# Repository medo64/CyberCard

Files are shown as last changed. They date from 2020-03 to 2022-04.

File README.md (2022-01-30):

[CyberCard](https://medo64.com/cybercard/)
==========================================

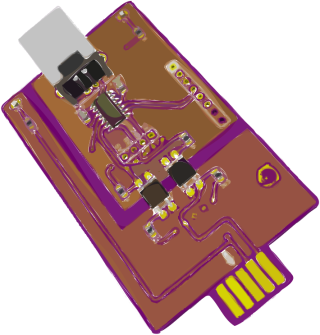
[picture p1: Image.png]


This USB device will show up on your system as a serial device and allow for a
fully isolated serial communication with CyberPower UPS devices that have support
for RMCARD202/RMCARD205 interface.

It was inspired with [Jeff Mayes Serial Interface](https://www.jmayes.com/cyberpower-backup-serial-protocol-and-interface/)
and wouldn't be possible without his extensive research.

To connect to the device, access serial device using 2400,8,N,1 (2,400 baud rate,
8 data bits, no parity, 1 stop bit) parameters. Protocol is described [here](PROTOCOL.md).

Tested devices:
* OR500LCDRM1U
* OR700LCDRM1U

---

*You can check my blog and other projects at [www.medo64.com](https://www.medo64.com/electronics/).*

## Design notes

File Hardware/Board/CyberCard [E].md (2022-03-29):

### CyberCard Parts ###

|  # | Part | RefDes  | Part Number | Alternate |
|---:|---|---|---|---|
|  1 | C 100nF X7R 16V (0805) | C4-C5 | 1276-1003-1-ND | 1276-2444-1-ND |
|  1 | C 470nF X7R 16V (0805) | C4-C5 | 1276-1074-1-ND | 1276-1199-1-ND |
|  2 | DS LED (0805) | DS1-DS2 | 475-1278-1-ND | L171L-LWC-TR |
|  1 | J USB B, horizontal | J1 | ED2982-ND | ED2983-ND |
|  3 | R 1.0K 0.125W (0805) | R1-R3 | RMCF0805FT1K00CT-ND | RMCF0805JT1K00CT-ND |
|  3 | R 2.2K 0.125W (0805) | R4-R6 | RMCF0805FT3K30CT-ND | RMCF0805JT3K30CT-ND |
|  1 | U MCP2221A-I/SL (SOIC-14) | U1 | MCP2221A-I/SL | MCP2221-I/SL-ND |
|  2 | U PC817C (SMD-4) | U2-U3 | 732-140817143200CT-ND | ISP817CXSMCT-ND |

#### Board Size ####

| | Dimensions | Area | Thickness |
|---|---|---|---|
| PCB |  75.0 x 42.5 mm | 5.0 in² | 1.6 mm |
| Panel |  54.0 x 36.5 mm | 3.1 in² | 1.6 mm |

#### Power ####

| Property | Value  |
|---|---:|
| Voltage  | 5 V |
| Current  | 100 mA |

### TTL UART Board ###

If only TTL UART access is required, the following components should be omitted:
  * C1
  * C2
  * DS1
  * J1
  * R3
  * U1

Instead of the components used, 4-pin male right-angle header should be placed
with a standard 5V USB to TTL serial cable connected to it. While 5V TTL cable
is preferred, the device should work with 3.3V TTL cable too.

A dab of hot glue is suggested on the connection to prevent accidental unplug.

On the computer side, serial port should be accessed using the following serial
port parameters: 2400,8,N,1.

### Microcontroller Controlled Board

If one desires more flexibility, MCP2221A UART can be replaced by pin-compatible
PIC16F1454 or PIC16F1455. This allows for a bit more flexibility when connecting
to UPS (e.g. no need to care about baud rate). Firmware is available as part of
this project.

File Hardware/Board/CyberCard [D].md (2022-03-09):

### CyberCard Parts ###

|  # | Part | RefDes  | Part Number | Alternate |
|---:|---|---|---|---|
|  2 | C 100nF X7R 16V (0805) | C4-C5 | 1276-1003-1-ND | 1276-2444-1-ND |
|  2 | C 470nF X7R 16V (0805) | C4-C5 | 1276-1074-1-ND | 1276-1199-1-ND |
|  2 | DS LED (0805) | DS1-DS2 | 475-1278-1-ND | L171L-LWC-TR |
|  1 | J USB B, horizontal | J1 | ED2982-ND | ED2983-ND |
|  6 | R 1.0K 0.125W (0805) | R1-R6 | RMCF0805FT1K00CT-ND | RMCF0805JT1K00CT-ND |
|  1 | U MCP2221A-I/SL (SOIC-14) | U1 | MCP2221A-I/SL | MCP2221-I/SL-ND |
|  2 | U PC817C (SMD-4) | U2-U3 | 732-140817143200CT-ND | ISP817CXSMCT-ND |
|  1 | VR L78L05ACD13TR (SO-8) | VR1 | 497-1180-1-ND | MC78L05ACDR2GOSCT-ND |

#### Board Size ####

| | Dimensions | Area | Thickness |
|---|---|---|---|
| PCB |  75.0 x 42.5 mm | 5.0 in² | 1.6 mm |
| Panel |  54.0 x 36.5 mm | 3.1 in² | 1.6 mm |

#### Power ####

| Property | Value  |
|---|---:|
| Voltage  | 5 V |
| Current  | 100 mA |

### TTL UART Board ###

If only TTL UART access is required, the following components should be omitted:
  * C1
  * C3
  * DS1
  * J1
  * R3
  * U1

Instead of the components used, 4-pin male right-angle header should be placed
with a standard 5V USB to TTL serial cable connected to it. While 5V TTL cable
is preferred, the device should work with 3.3V TTL cable too.

A dab of hot glue is suggested on the connection to prevent accidental unplug.

On the computer side, serial port should be accessed using the following serial
port parameters: 2400,8,N,1.

### Microcontroller Controlled Board

If one desires more flexibility, MCP2221A UART can be replaced by pin-compatible
PIC16F1454 or PIC16F1455. This allows for a bit more flexibility when connecting
to UPS (e.g. no need to care about baud rate). Firmware is available as part of
this project.

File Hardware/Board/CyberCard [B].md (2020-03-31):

### CyberCard ###

#### Input ####

Voltage: 5 V ±10%
Current: 100 mA

#### Parts ####

|  # | Part | RefDes  | Preferred Part Number |
|---:|---|---|---|
|  4 | C 100nF 25V X7R (0805) | C1-C4 | 399-1170-1-ND |
|  3 | C 470nF 25V X7R (0805) | C5-C7 | 1276-6480-1-ND |
|  2 | DS LED (0805) | DS1-DS2 | 475-1415-1-ND |
|  1 | J USB B, horizontal | J1 | ED2983-ND |
|  1 | J Header (4w) | J2 | S9016E-04-ND |
|  1 | L Ferrite 40Ohm (0805) | L1 | 445-2201-1-ND |
|  2 | R 3.3K 0.125W (0805) | R1-R2 | RMCF0805FT3K30CT-ND |
|  1 | U MCP2221A (TSSOP-14) | U1 | MCP2221A-I/ST-ND |
|  1 | U Si8421 (SOIC-8) | U2 | 336-1755-5-ND |
|  1 | VR L78L05ACD13TR (SO-8) | VR1 | 497-1180-1-ND |

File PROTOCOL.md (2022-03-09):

[CyberCard Protocol](https://medo64.com/cybercard/)
===================================================

## Commands

Each command must be terminated with `<CR>`. Response will be start with `#`
(hash) character and will end with `<CR>`. Invalid commands will result in
`#-3<CR>` response.

### Current information (D)

This command will retrieve current UPS input/output information.

| Send | Response (example) |
|---|---|
| `D<CR>` | `#I121.0O121.0L000B088F060.1R073S<0x80><0x84><0x90><0x80><0x80><CR>` |

Response will be a single line with the following fields.

| Field | Example  | Description |
|---|---|---|
| Input voltage (V)  | `I121.0` | Current input voltage |
| Output voltage (V) | `O121.0` | Current output voltage |
| Load (%) | `L000` | Load as compared to maximum UPS power |
| Battery (%) | `B088` | Battery charge status |
| Frequency (Hz) | `F060.1` | Measured line frequency |
| Run time (minutes) | `R073` | Estimated runtime upon power loss |
| Status bits | | See table below |

The following are known status bits.

| Byte | Bit | Meaning (0:no 1:yes) |
|-----:|----:|---|
| 1 | 2 | Power-on pending |
| 1 | 3 | Power-off pending |
| 1 | 4 | Test in progress |
| 1 | 5 | Currently beeping |
| 1 | 6 | Battery capacity low |
| 1 | 7 | Battery in-use |
| 2 | 4 | External power on |
| 3 | 5 | Battery charging |
| 3 | 7 | Battery full |
| 5 | 7 | Powered off |

### Buzzer

This command will change buzzer status on/off.

| Send | Response (example) | Description |
|---|---|---|
| `C7:0<CR>` | `#0<CR>` | Buzzer is set to off |
| `C7:1<CR>` | `#0<CR>` | Buzzer is set to on |

### Model Information

These commands will output UPS model information.

| Send | Response (example) | Description |
|---|---|---|
| `P1<CR>` | `#12,140,90,10,300<CR>` | Unknown, Voltage(max), Voltage(min), VoltageRange(%), Unknown |
| `P2<CR>` | `#0700,0400,120,057,063<CR>` | Power(VA), Power(W), Voltage(nominal), Frequency(min), Frequency(max) |
| `P3<CR>` | `#06.0,2x1,009.0,00<CR>` | BatteryVoltage(nominal), Battery(layout), BatteryVA(nominal), Unknown |
| `P4<CR>` | `#OR700LCDRM1U,BFE7103_8S1,000000000000,CyberPower<CR>` | Product name, Firmware, SerialNumber, Manufacturer |
| `P5<CR>` | `#120<CR>` | Voltage(nominal) |
| `P6<CR>` | `#140<CR>` | Voltage(max) |
| `P7<CR>` | `#90<CR>` | Voltage(min) |
| `P8<CR>` | `#10,20,30,40,50,60,70,80,90<CR>` | Unknown |
| `P9<CR>` | `#<0xC3><0x87><0xE0><CR>` | Unknown |

### Power Control

These commands will control UPS power state.

| Send | Response | Description |
|---|---|---|
| `S<CR>` | `#0<CR>` | Immediate power off |
| `S(NN)<CR>` | `#0<CR>` | Power off after `(NN)` minutes |
| `S00R0000<CR>` | `#0<CR>` | Immediate power off followed by power on |
| `S(NN)R(MMMM)<CR>` | `#0<CR>` | Power off after `(NN)` minutes, power on after `(MMMM)` minutes |
| `W<CR>` | `#0<CR>` | Power on |
| `C<CR>` | `#0<CR>` | Cancel power off |

## Battery Test

These commands will control battery test.

| Send | Response | Description |
|---|---|---|
| `T<CR>` | `#0<CR>` | Quick test (switch to battery for a few seconds) |
| `TL<CR>` | `#0<CR>` | Start deep battery test |
| `CT<CR>` | `#0<CR>` | Cancel deep battery test |

## Physical Connection

Internal communication is routed over 10-pin connector at 2400,8,N,1 RS-232 at
5V TTL levels. Only 4 wires are fully connected to USP board. Middle two pins
are connected to internal connector but without any wires.

| Pin | Location | Description |
|----:|:---:|---|
| 1 |  Bottom  | GND |
| 2 | Top | RX (to UPS) |
| 3 |  Bottom  | TX (from UPS) |
| 4 | Top | +12V |
| 5 |  Bottom  | Not used |
| 6 | Top | Not used |
| 7 |  Bottom  | Not connected |
| 8 | Top | Not connected |
| 9 |  Bottom  | Not connected |
|  10 | Top | Not connected |

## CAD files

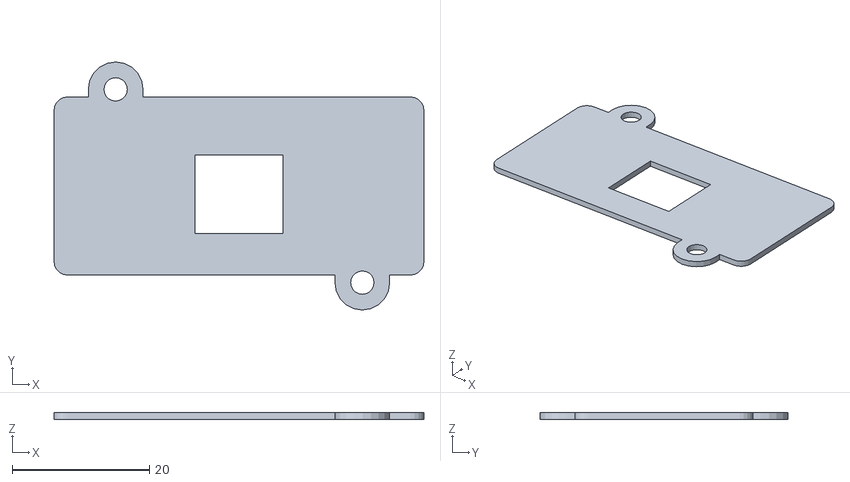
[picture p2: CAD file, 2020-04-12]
Hardware/Board/CyberCard Cover [E].stl
54.0 x 36.2 x 1.00

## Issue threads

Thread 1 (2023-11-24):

Sale? Gerber files?

raleighlittles, 2023-11-24:
First off I wanted to say thanks for this project. I actually came across James' blog post several years ago and remarked at how neat it was, it's cool that there's finally a direct USB option.

I have a few questions:

Would you be open to selling pre-assembled kits? [Tindie](https://www.tindie.com/) is basically the standard marketplace for something like this, but even Etsy or Ebay could work.

If the answer to that question is no, then, would you be comfortable with at least providing the Gerber & BOM files so that people can order their own kits? Here's some [info on exporting Gerber files from diptrace](https://www.pcbway.com/blog/PCB_Layout_Software/How_to_generate_Gerber_files_from_DipTrace.html)

medo64, 2023-12-22:
Hi,

I won't be making any pre assembled kits for sales. Mostly because CyberPower can change their design at any point in time and I am not going to invest time and money into testing it with their newer models. Project scratched my itch and that's was unfortunately all the time I was ready to sink into it.

That said, I made gerbers are available [for download](https://github.com/medo64/CyberCard/releases/tag/vD2204) if people don't want to deal with DipTrace.

Closed 2023-12-22.

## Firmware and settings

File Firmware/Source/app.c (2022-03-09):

#include <stdint.h>
#include "hardware.h"
#include "io.h"
#include "state.h"
#include "uart.h"

#include "Microchip/usb.h"
#include "Microchip/usb_device.h"
#include "Microchip/usb_device_cdc.h"

#define LED_TIMEOUT       2000
#define LED_TIMEOUT_NONE  65535
uint16_t LedTimeout = LED_TIMEOUT_NONE;

void main(void) {
    init();
    io_init();

    io_splash();

    uart_init();
    uart_setup(2400);

    USBDeviceInit();
    USBDeviceAttach();

    io_activity_led_on();

    while(true) {
        if (LedTimeout != LED_TIMEOUT_NONE) {
            if (LedTimeout == 0) {
                io_activity_led_on();
                LedTimeout = LED_TIMEOUT_NONE;
            } else {
                LedTimeout--;
            }
        }

        if (USBGetDeviceState() < CONFIGURED_STATE) { continue; }
        if (USBIsDeviceSuspended() == true) { continue; }


        // UART receive
        while ((UartReadBufferCount < UART_READ_BUFFER_MAX) && uart_tryReadByte(&UartReadBuffer[UartReadBufferEnd])) {
            io_activity_led_off();
            LedTimeout = LED_TIMEOUT;

            UartReadBufferEnd = (UartReadBufferEnd + 1) % UART_READ_BUFFER_MAX;
            UartReadBufferCount++;
        }

        // UART send
        if ((UartWriteBufferCount > 0) && uart_tryWriteByte(UartWriteBuffer[UartWriteBufferStart])) {
            io_activity_led_off();
            LedTimeout = LED_TIMEOUT;

            UartWriteBufferStart = (UartWriteBufferStart + 1) % UART_WRITE_BUFFER_MAX;
            UartWriteBufferCount--;
        }

        // USB receive
        uint8_t usbCount = getsUSBUSART(UsbReadBuffer, USB_READ_BUFFER_MAX); //until the buffer is free.
        if (usbCount > 0) {
            io_activity_led_off();
            LedTimeout = LED_TIMEOUT;

            //copy buffer
            for (int i=0; i<usbCount; i++) {
                UartWriteBuffer[UartWriteBufferEnd] = UsbReadBuffer[i];
                if (UartWriteBufferCount < UART_WRITE_BUFFER_MAX) {
                    UartWriteBufferEnd = (UartWriteBufferEnd + 1) % UART_WRITE_BUFFER_MAX;
                    UartWriteBufferCount++;
                }
            }
        }

        // USB send
        if(UartReadBufferCount > 0) {
            io_activity_led_off();
            LedTimeout = LED_TIMEOUT;

            uint8_t usbCount = 0;
            for (int i=0; i<USB_WRITE_BUFFER_MAX; i++) {
                if (UartReadBufferCount > 0) {
                    UsbWriteBuffer[i] = UartReadBuffer[UartReadBufferStart];
                    UartReadBufferStart = (UartReadBufferStart + 1) % UART_READ_BUFFER_MAX;
                    UartReadBufferCount--;
                    usbCount++;
                } else {
                    break;
                }
            }

            putUSBUSART(&UsbWriteBuffer[0], usbCount);
        }

        CDCTxService();
    }
}


void interrupt SYS_InterruptHigh(void) {
    USBDeviceTasks();
}

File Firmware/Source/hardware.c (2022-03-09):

#include <xc.h>
#include <pic16f1454.h>
#include "hardware.h"


void init(void) {
    interrupt_disable();

    // Oscillator
    OSCCONbits.IRCF = 0b1111;  // 16 MHz or 48 MHz HF
    OSCCONbits.SPLLMULT = 1;  // 3x PLL is enabled
    OSCCONbits.SPLLEN = 1;  // PLL is enabled
    ACTCONbits.ACTSRC = 1;  // The HFINTOSC oscillator is tuned using Fll-speed USB events
    ACTCONbits.ACTEN = 1;  // ACT is enabled, updates to OSCTUNE are exclusive to the ACT

    // IO * A5:led  A4:led2  A1:d-  A0:d+   C5:rx  C4:tx
    LATA = 0b00000000;  // A5:off  A4:off
    LATC = 0b00000000;
    TRISA = 0b00110000;  // A5:input  A4:input
    TRISC = 0b00100000;  // C5:rx  C4:tx

    interrupt_enable();
}

void wait_short(void) {
    __delay_ms(100);
}

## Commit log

2020-03-29 Removing reset circuit
2020-03-29 Moving board designators a bit
2020-03-31 Corrected resistor value
2020-04-11 Tented ground pad extensions
2020-04-11 Updated RX/TX LED setup
2020-04-11 Updated UART connector
2020-04-11 Reworked edge connector
2020-04-11 Updated edge connector
2020-04-12 Added cover template
    [CyberCard Cover [C].stl]
2020-04-13 Added fuse on UPS side
2020-04-13 Changed fuse to 1206
2020-04-13 Moving fuse as UPS side is already protected by VR
2020-04-15 Increased board size to 75x43 (was 71x43)
2020-04-17 Changed UART connector pinout
    [CyberCard Cover [D].stl]
2020-04-17 Added diode instead of fuse
2020-04-17 Updated board part list
2020-04-17 Added extra LED that lights up even without main IC
2020-04-17 Moving LEDs a bit
2020-04-17 Refactoring diode a bit
2020-04-23 Wider connector (15.24 instead of 15)
2020-05-02 Aded extra LED and refactoring board size
2020-05-02 Narrowed dimensions to 42mm
2020-05-02 Shorten length to 74mm
2020-05-02 Added series resistor to isolator
2020-05-02 Extended length to 76 mm
2020-05-19 Less exposed connector on edge connector side
2020-05-20 Separated board files
2020-05-20 Shortened card by 0.5mm
2022-01-23 Updated pins for activity LED
2022-01-24 Added cover in PCB form
2022-01-27 Moved TTL connector to middle
2022-01-27 Explaining TTL cable version
2022-01-27 Fixing silkscreen
2022-01-27 Moving LEDs around
2022-01-29 Updated cover PCB
2022-01-29 Added cable cover
2022-03-08 Rotated LED
2022-03-09 Activity LED is on by default
2022-03-09 Changed PIC to UART by default
2022-03-27 Added PCB drawing
2022-03-27 Removing voltage regulator
    [CyberCard Cover [E].stl]
2022-03-29 Refactored to use 12V line directly
